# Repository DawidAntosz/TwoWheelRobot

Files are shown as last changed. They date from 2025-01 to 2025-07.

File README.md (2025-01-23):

# TwoWheelRobot
Differential wheeled robot

This project is focused on building a two-wheel differential robot with the ability to control and navigate in area.

## Project Structure
The project is organized into the following directories:

- `src/`: Contains the source code for the project.
  - `arduino/`: Source code using the Arduino framework (PlatformIO).
  - `esp_rtos_sdk/`: (For future development of the project using the ESP8266 RTOS SDK).

##### Control page:
<p align="center">
<!--   <img src="https://github.com/user-attachments/assets/38fbeb17-e8d2-4559-942d-c8bff26c4116" width="600" />  -->
   
<!--   <img src="" width="600" />  -->
</p>

##### Robot V1:

obraz

##### Math model
<p align="center">
   

</p>

$$
\dot{x} = \frac{R}{2}(v_r + v_\ell)\cos\phi
$$
$$
\dot{y} = \frac{R}{2}(v_r + v_\ell)\sin\phi
$$
$$
\dot{\phi} = \frac{R}{L}(v_r - v_\ell)
$$

$$
\dot{x} = v\cos\phi
$$
$$
\dot{y} = v\sin\phi
$$
$$
\dot{\phi} = \omega
$$

$$
v = \frac{R}{2}(v_r + v_\ell) \implies \frac{2v}{R} = v_r + v_\ell
$$

$$
\omega = \frac{R}{L}(v_r - v_\ell) \implies \frac{\omega L}{R} = v_r - v_\ell
$$

$$
\ v_r = \\frac{2v + \\omega L}{2R} \\\ 
$$
$$
 v_l = \\frac{2v - \\omega L}{2R} \
$$

Description parameters:
- \( v_r \): the speed of the right wheel
- \( v_\ell \): the speed of the left wheel
- \( R \): the radius of the wheel
- \( L \): the distance between the wheels
- \( $$\omega$$ \): the angular velocity of the robot

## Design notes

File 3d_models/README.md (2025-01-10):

# TwoWheelRobot
Differential wheeled robot

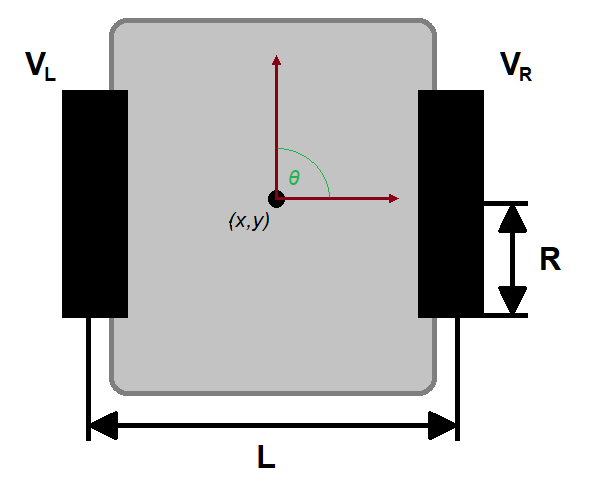
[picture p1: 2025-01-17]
docs/robot.png

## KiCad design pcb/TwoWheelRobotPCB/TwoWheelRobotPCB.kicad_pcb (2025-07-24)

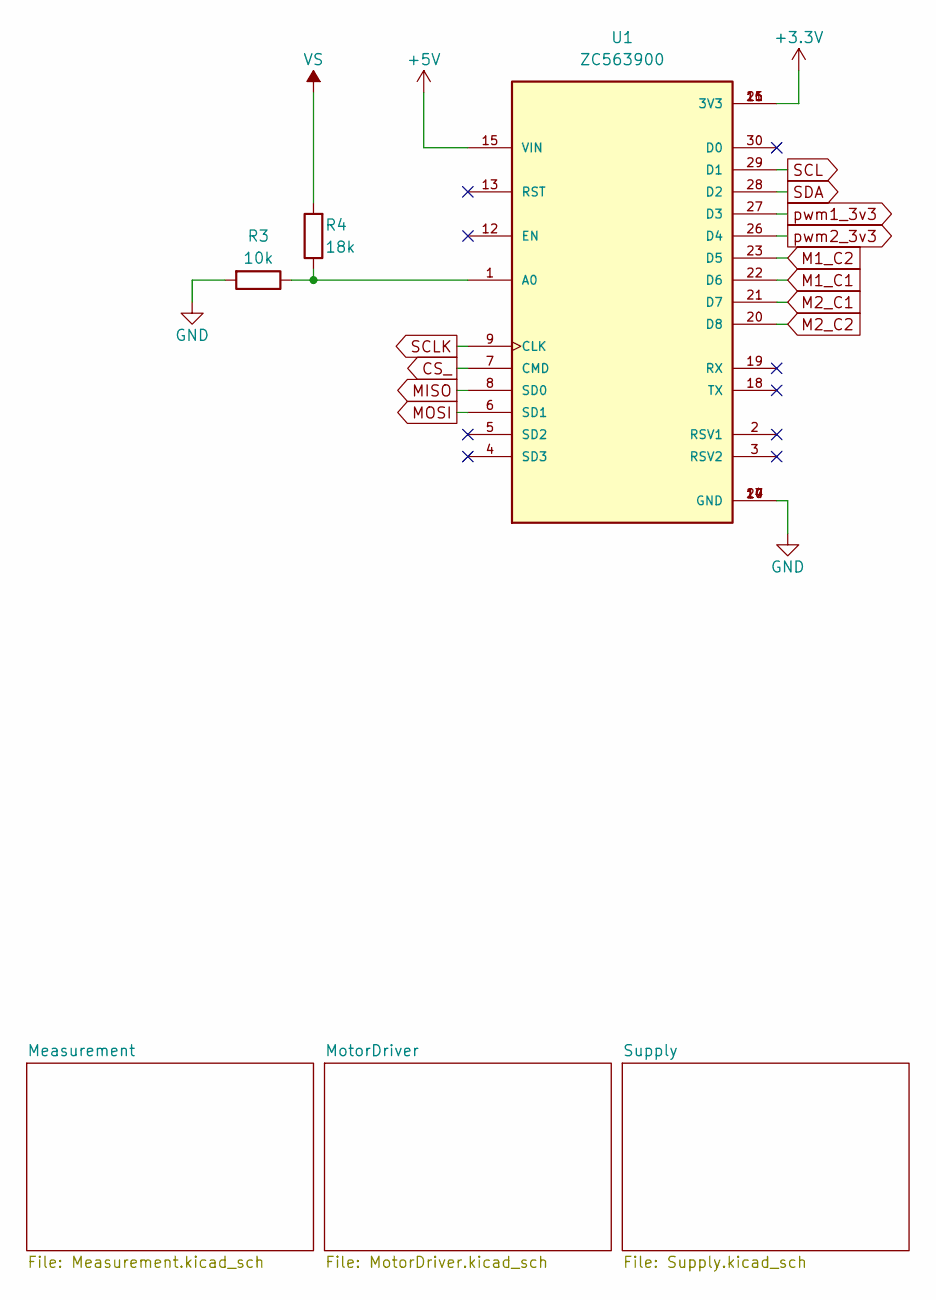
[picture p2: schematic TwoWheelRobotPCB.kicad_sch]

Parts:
R3: 10k; R_0805_2012Metric
R4: 18k; R_0805_2012Metric
U1: ZC563900; MODULE_ZC563900; PARTREV 1.0

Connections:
+3V3: U1.11 (3V3), U1.16 (3V3), U1.25 (3V3); also elsewhere on the board
+5V: U1.15 (VIN); also elsewhere on the board
CS_: U1.7 (CMD); also elsewhere on the board
GND: R3.2, U1.10 (GND), U1.14 (GND), U1.17 (GND), U1.24 (GND); also elsewhere on the board
M1_C1: U1.22 (D6); also elsewhere on the board
M1_C2: U1.23 (D5); also elsewhere on the board
M2_C1: U1.21 (D7); also elsewhere on the board
M2_C2: U1.20 (D8); also elsewhere on the board
MISO: U1.8 (SD0); also elsewhere on the board
MOSI: U1.6 (SD1); also elsewhere on the board
unnamed: R3.1, R4.1, U1.1 (A0)
SCL: U1.29 (D1); also elsewhere on the board
SCLK: U1.9 (CLK); also elsewhere on the board
SDA: U1.28 (D2); also elsewhere on the board
VS: R4.2; also elsewhere on the board
pwm1_3v3: U1.27 (D3); also elsewhere on the board
pwm2_3v3: U1.26 (D4); also elsewhere on the board

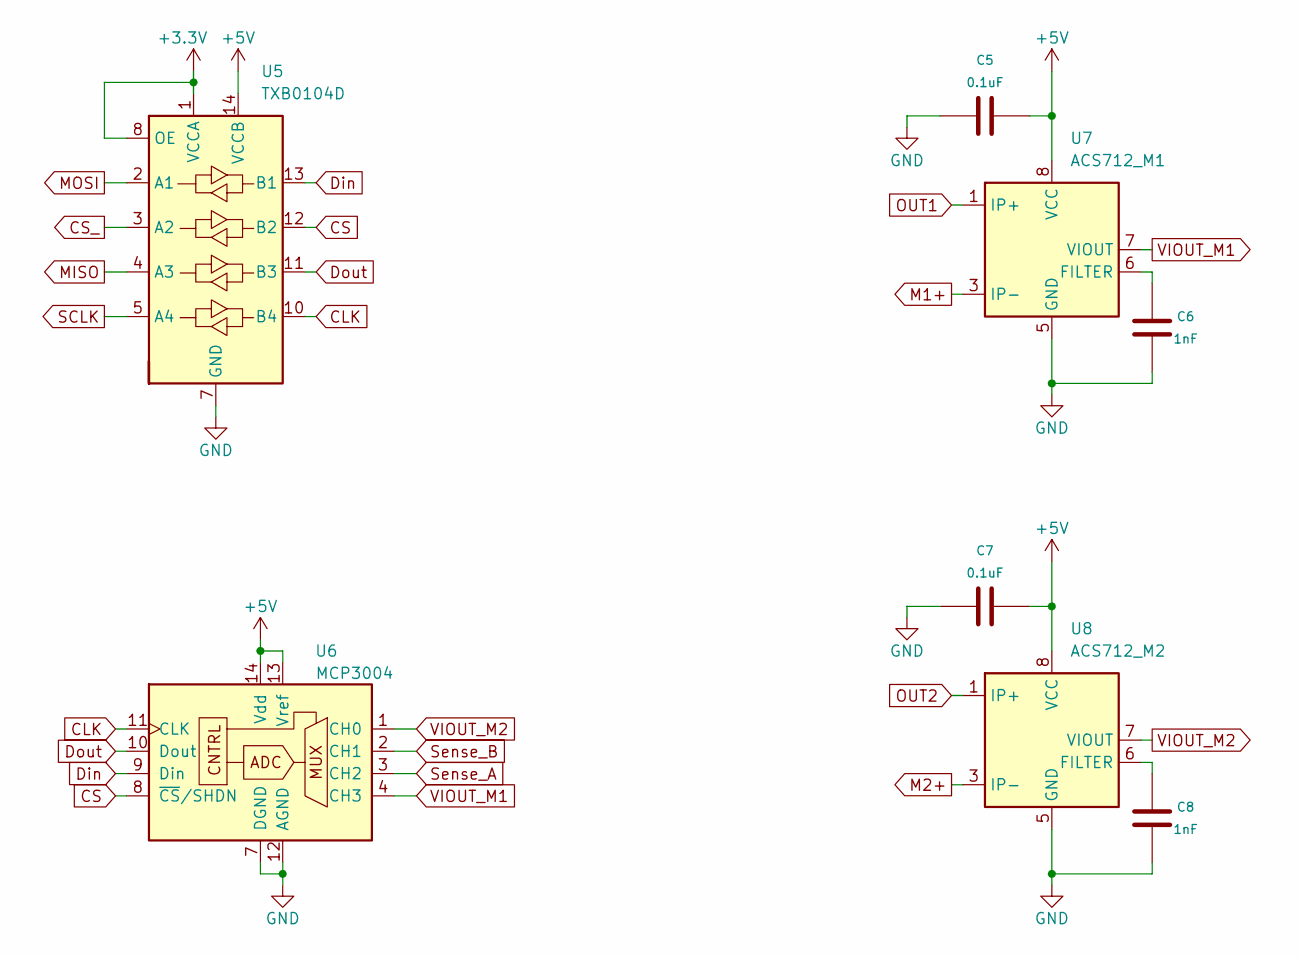
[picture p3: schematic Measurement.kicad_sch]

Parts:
C5, C7: 0.1uF; C_0805_2012Metric
C6, C8: 1nF; C_0805_2012Metric
U5: TXB0104D; SOP65P640X120-14N
U6: MCP3004; SOIC127P600X175-14N
U7: ACS712_M1; SOIC-8_3.9x4.9mm_P1.27mm
U8: ACS712_M2; SOIC-8_3.9x4.9mm_P1.27mm

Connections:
+3V3: U5.1 (VCCA), U5.8 (OE); also elsewhere on the board
+5V: C5.1, C7.1, U5.14 (VCCB), U6.13 (Vref), U6.14 (Vdd), U7.8 (VCC), U8.8 (VCC); also elsewhere on the board
CLK: U5.10 (B4), U6.11 (CLK)
CS: U5.12 (B2), U6.8 (~CS/SHDN)
CS_: U5.3 (A2); also elsewhere on the board
Din: U5.13 (B1), U6.9 (Din)
Dout: U5.11 (B3), U6.10 (Dout)
GND: C5.2, C6.2, C7.2, C8.2, U5.7 (GND), U6.7 (DGND), U6.12 (AGND), U7.5 (GND), U8.5 (GND); also elsewhere on the board
M1+: U7.3 (IP-), U7.4 (IP-); also elsewhere on the board
M2+: U8.3 (IP-), U8.4 (IP-); also elsewhere on the board
MISO: U5.4 (A3); also elsewhere on the board
MOSI: U5.2 (A1); also elsewhere on the board
unnamed: C6.1, U7.6 (FILTER)
unnamed: C8.1, U8.6 (FILTER)
OUT1: U7.1 (IP+), U7.2 (IP+); also elsewhere on the board
OUT2: U8.1 (IP+), U8.2 (IP+); also elsewhere on the board
SCLK: U5.5 (A4); also elsewhere on the board
Sense_A: U6.3 (CH2); also elsewhere on the board
Sense_B: U6.2 (CH1); also elsewhere on the board
VIOUT_M1: U6.4 (CH3), U7.7 (VIOUT)
VIOUT_M2: U6.1 (CH0), U8.7 (VIOUT)

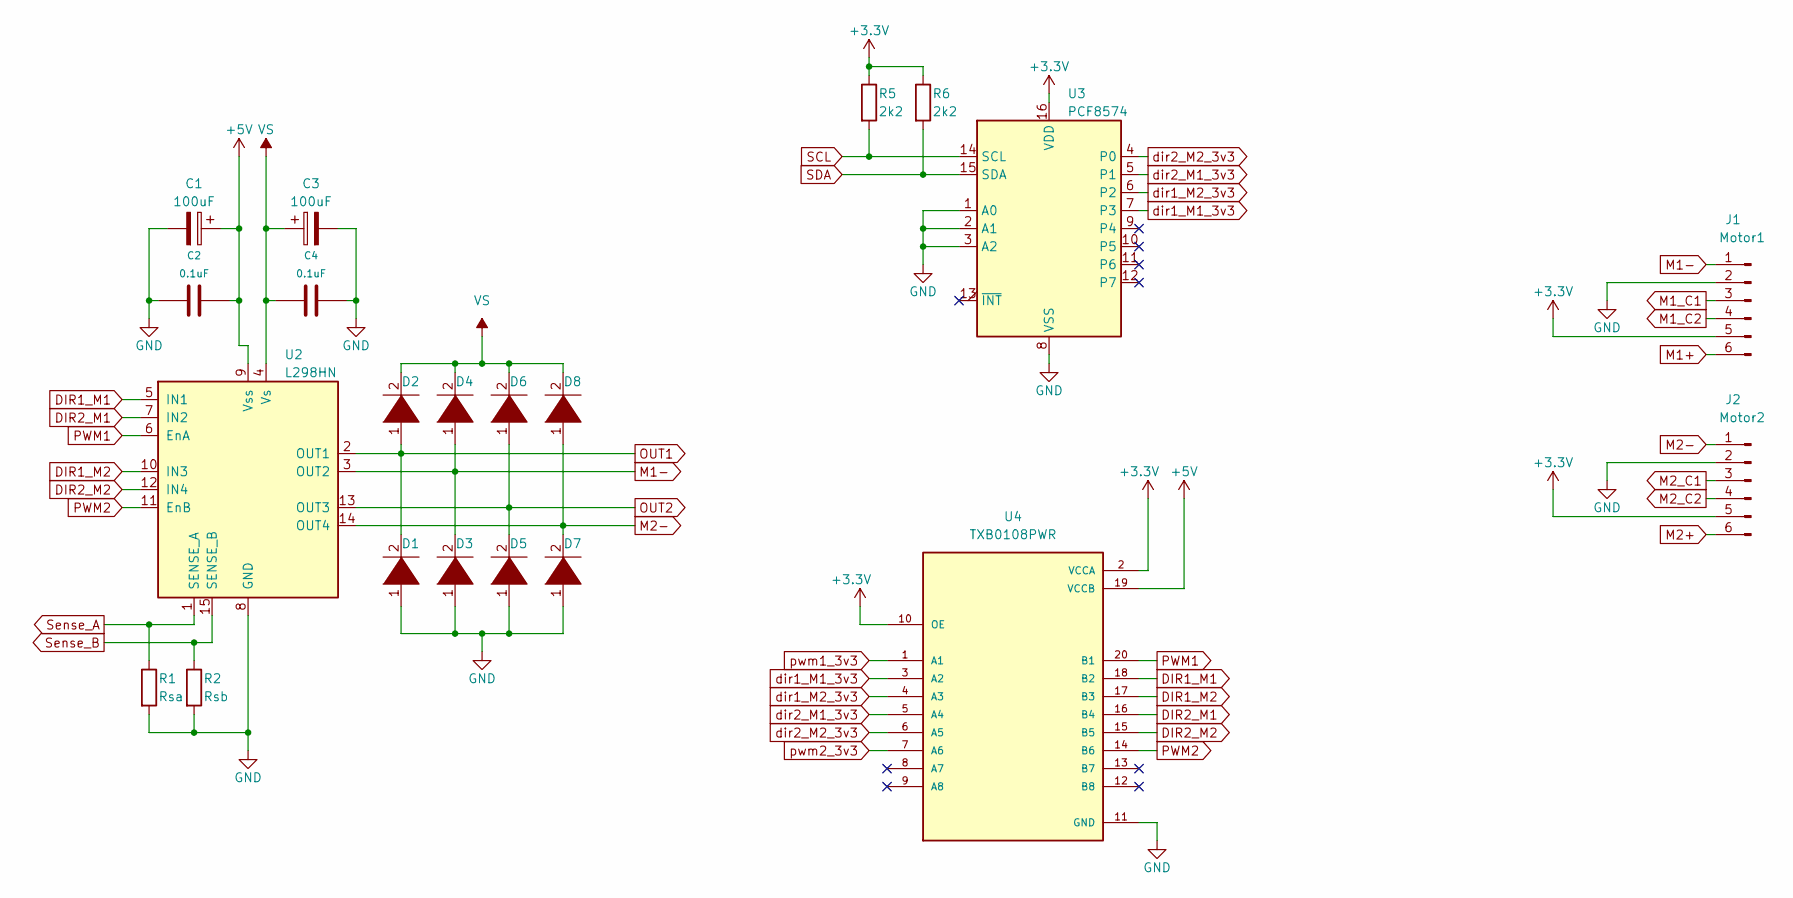
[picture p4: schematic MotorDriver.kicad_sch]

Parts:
C1, C3: 100uF; CP_Radial_D6.3mm_P2.50mm
C2, C4: 0.1uF; C_Disc_D4.3mm_W1.9mm_P5.00mm
D1, D2, D3, D4, D5, D6, D7, D8: DIODE; D_A-405_P10.16mm_Horizontal
J1: Motor1; PinHeader_1x06_P2.54mm_Vertical
J2: Motor2; PinHeader_1x06_P2.54mm_Vertical
R1: Rsa; R_0805_2012Metric
R2: Rsb; R_0805_2012Metric
R5, R6: 2k2; R_0805_2012Metric
U2: L298HN; TO-220-15_P2.54x2.54mm_StaggerOdd_Lead4.58mm_Vertical
U3: PCF8574; SO16W
U4: TXB0108PWR; SOP65P640X120-20N; PARTREV H

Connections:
+3V3: J1.5, J2.5, R5.1, R6.1, U3.16 (VDD), U4.2 (VCCA), U4.10 (OE); also elsewhere on the board
+5V: C1.1, C2.1, U2.9 (Vss), U4.19 (VCCB); also elsewhere on the board
DIR1_M1: U2.5 (IN1), U4.18 (B2)
DIR1_M2: U2.10 (IN3), U4.17 (B3)
DIR2_M1: U2.7 (IN2), U4.16 (B4)
DIR2_M2: U2.12 (IN4), U4.15 (B5)
GND: C1.2, C2.2, C3.2, C4.1, D1.1 (K), D3.1 (K), D5.1 (K), D7.1 (K), J1.2, J2.2, R1.2, R2.2, U2.8 (GND), U3.1 (A0), U3.2 (A1), U3.3 (A2), U3.8 (VSS), U4.11 (GND); also elsewhere on the board
M1+: J1.6; also elsewhere on the board
M1-: D3.2 (A), D4.1 (K), J1.1, U2.3 (OUT2)
M1_C1: J1.3; also elsewhere on the board
M1_C2: J1.4; also elsewhere on the board
M2+: J2.6; also elsewhere on the board
M2-: D7.2 (A), D8.1 (K), J2.1, U2.14 (OUT4)
M2_C1: J2.3; also elsewhere on the board
M2_C2: J2.4; also elsewhere on the board
OUT1: D1.2 (A), D2.1 (K), U2.2 (OUT1); also elsewhere on the board
OUT2: D5.2 (A), D6.1 (K), U2.13 (OUT3); also elsewhere on the board
PWM1: U2.6 (EnA), U4.20 (B1)
PWM2: U2.11 (EnB), U4.14 (B6)
SCL: R5.2, U3.14 (SCL); also elsewhere on the board
SDA: R6.2, U3.15 (SDA); also elsewhere on the board
Sense_A: R1.1, U2.1 (SENSE_A); also elsewhere on the board
Sense_B: R2.1, U2.15 (SENSE_B); also elsewhere on the board
VS: C3.1, C4.2, D2.2 (A), D4.2 (A), D6.2 (A), D8.2 (A), U2.4 (Vs); also elsewhere on the board
dir1_M1_3v3: U3.7 (P3), U4.3 (A2)
dir1_M2_3v3: U3.6 (P2), U4.4 (A3)
dir2_M1_3v3: U3.5 (P1), U4.5 (A4)
dir2_M2_3v3: U3.4 (P0), U4.6 (A5)
pwm1_3v3: U4.1 (A1); also elsewhere on the board
pwm2_3v3: U4.7 (A6); also elsewhere on the board

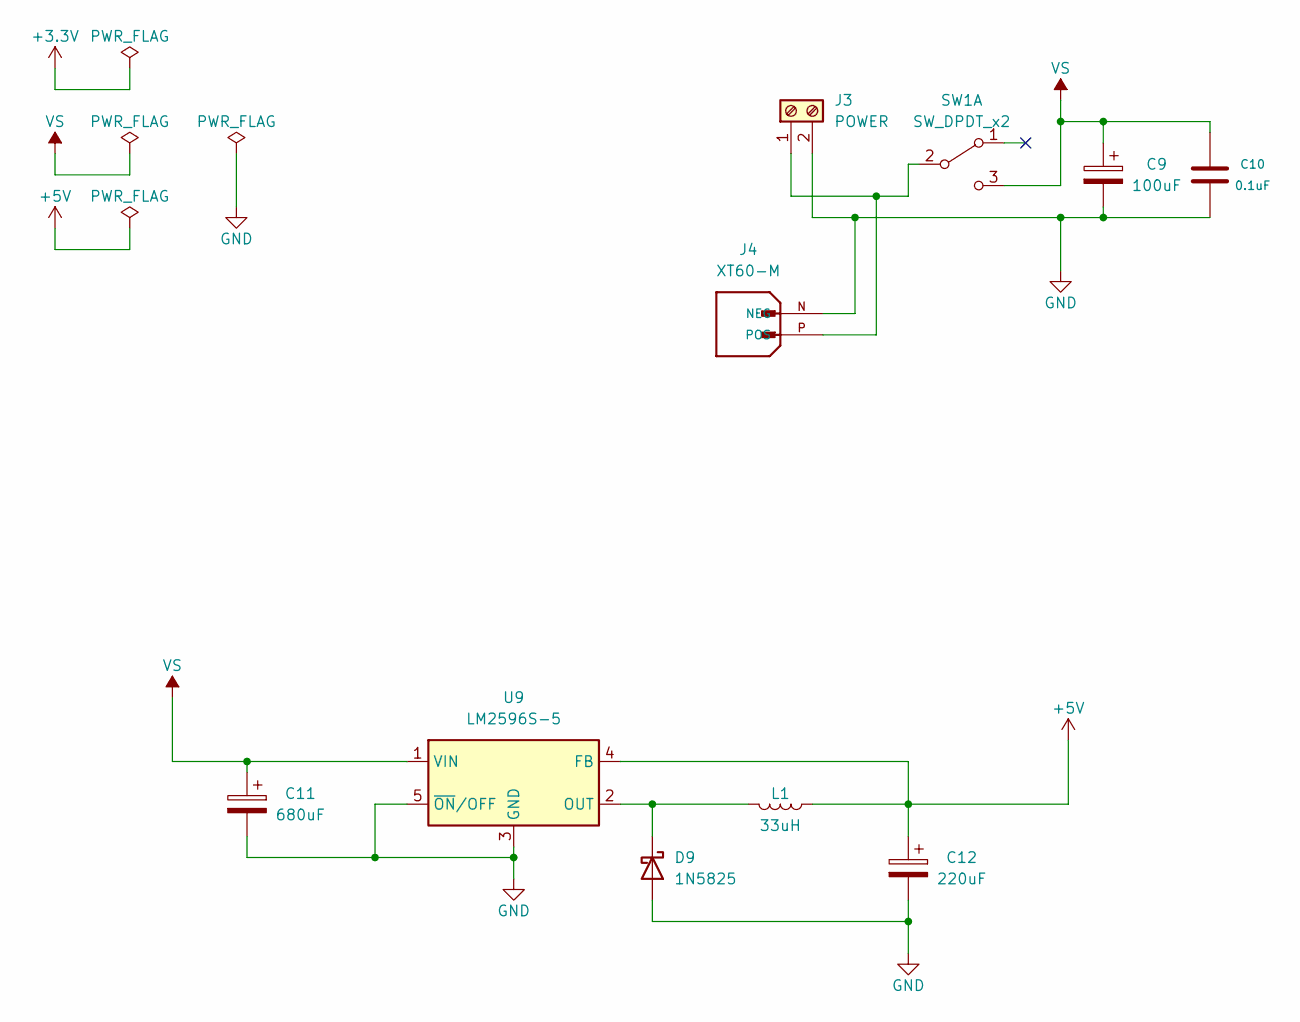
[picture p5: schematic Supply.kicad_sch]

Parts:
C9: 100uF; CP_Radial_D6.3mm_P2.50mm
C10: 0.1uF; C_Disc_D4.3mm_W1.9mm_P5.00mm
C11: 680uF; CP_Elec_8x6.9
C12: 220uF; CP_Elec_8x6.9
D9: 1N5825; D_2010_5025Metric_Pad1.52x2.65mm_HandSolder
J3: POWER; TerminalBlock_RND_205-00001_1x02_P5.00mm_Horizontal
J4: XT60-M; AMASS_XT60-M; PARTREV V1.2
L1: 33uH; L_Bourns_SRP1245A
SW1: SW_DPDT_x2; SW_PUSH_E-Switch_FS5700DP_DPDT
U9: LM2596S-5; TO-263-5_TabPin3

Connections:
+5V: C12.1, L1.1, U9.4 (FB); also elsewhere on the board
GND: C9.2, C10.1, C11.2, C12.2, D9.2 (A), J3.2, J4.N (NEG), U9.3 (GND), U9.5 (~ON/OFF); also elsewhere on the board
unnamed: D9.1 (K), L1.2, U9.2 (OUT)
unnamed: J3.1, J4.P (POS), SW1.2 (B)
VS: C9.1, C10.2, C11.1, SW1.3 (C), U9.1 (VIN); also elsewhere on the board

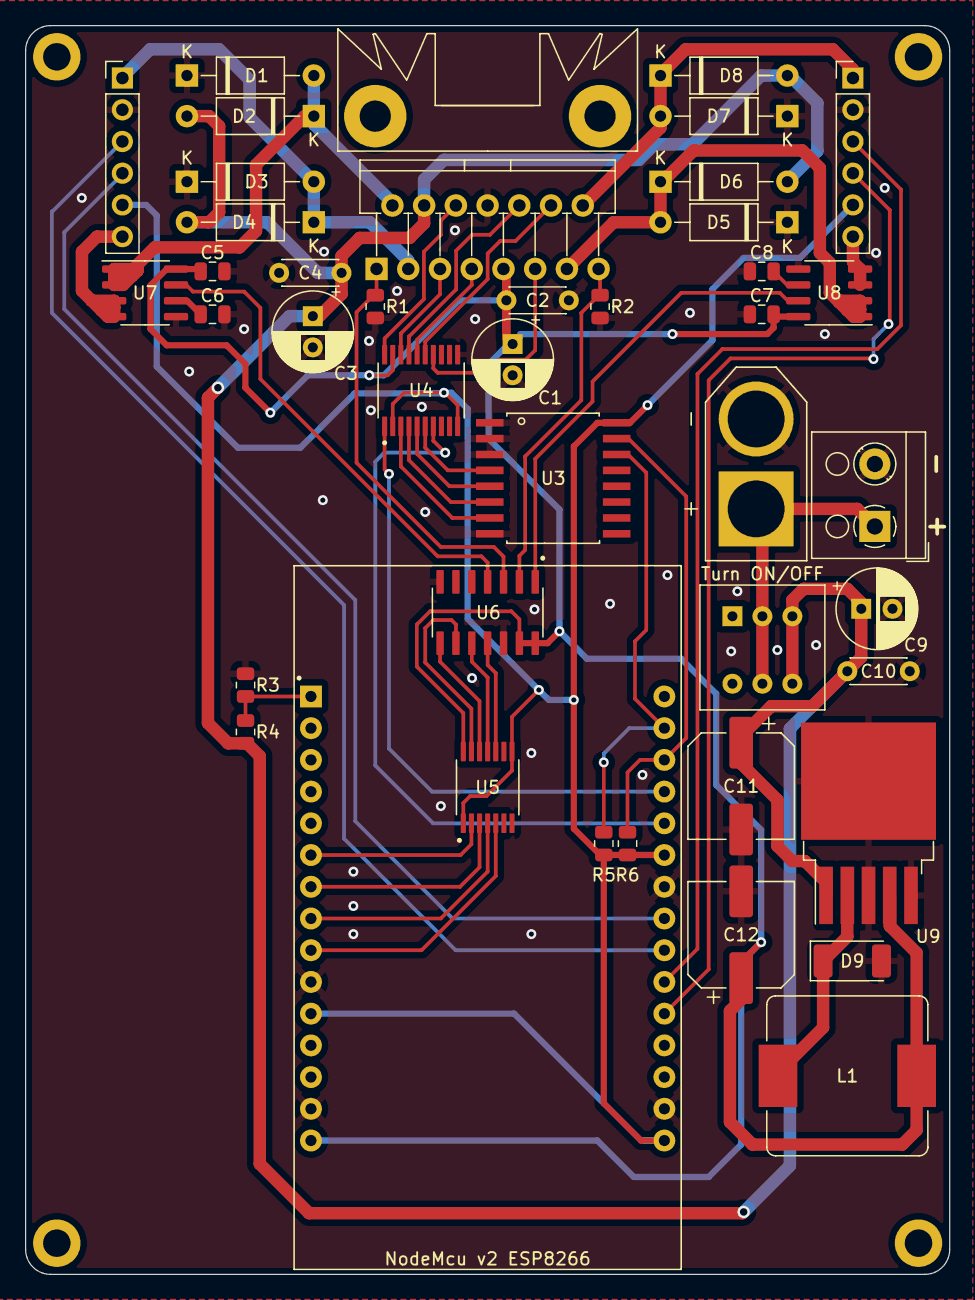
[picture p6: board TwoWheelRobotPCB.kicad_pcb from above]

Board: 2 copper layers, 74.0 x 100.0 mm, 42 parts (0 on the bottom side), 45 nets.

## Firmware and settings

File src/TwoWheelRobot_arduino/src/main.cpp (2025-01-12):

#include <Arduino.h>
#include "WiFiConfig.hpp"
#include "MotionController.hpp"
#include "WiFiManager.hpp"

MotionController motionController;
WiFiManager wifiManager;

void setup(void)
{ 
  Serial.begin(115200);
  motionController.init();

  wifiManager.begin(WiFiConfig::SSID, WiFiConfig::PASSWORD);
}

void loop(void) 
{
  wifiManager.handleServer();
  // Pose currentPoseCopy = motionController.readCurrentPose();
  // Serial.println("Main whlie current position:");
  
  // Serial.print("x:");
  // Serial.println(currentPoseCopy.x);
  
  // Serial.print("y:");
  // Serial.println(currentPoseCopy.y);

  // Serial.print("theta:");
  // Serial.println(currentPoseCopy.theta);

  delay(1000);
}

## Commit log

2025-01-11 calculate current position function
2025-01-23 robotView class && update pcb
    [TwoWheelRobotPCB.kicad_pcb, TwoWheelRobotPCB.kicad_sch]
2025-02-02 pcb update
    [Measurement.kicad_sch, MotorDriver.kicad_sch, Supply.kicad_sch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]
2025-02-02 update pcb
    [Measurement.kicad_sch, MotorDriver.kicad_sch, TwoWheelRobotPCB.kicad_pcb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]
2025-03-03 pcb finish
    [Measurement.kicad_sch, MotorDriver.kicad_sch, TwoWheelRobotPCB.kicad_pcb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]
